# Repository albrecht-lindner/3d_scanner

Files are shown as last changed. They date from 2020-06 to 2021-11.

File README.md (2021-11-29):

# 3d scanner under $40
This project proposes a 3d scanner for distances of up to roughly 10 meters. The scanner uses a smartphone and a line laser module to create colored point clouds. This repository contains hardware and software files.
<br>

The left  image shows the scanner mounted on a tripod and the right image shows the corresponding video frame captured by the smartphone. The horizontal disparity shift of the laser line visible in the video frame is related to the depth of the scene points.

<table style="width:100%; margin:0 auto; border: 0px;">
    <tr>
      <th>setup</th>
      <th>video frame</th> 
    </tr>
    <tr>
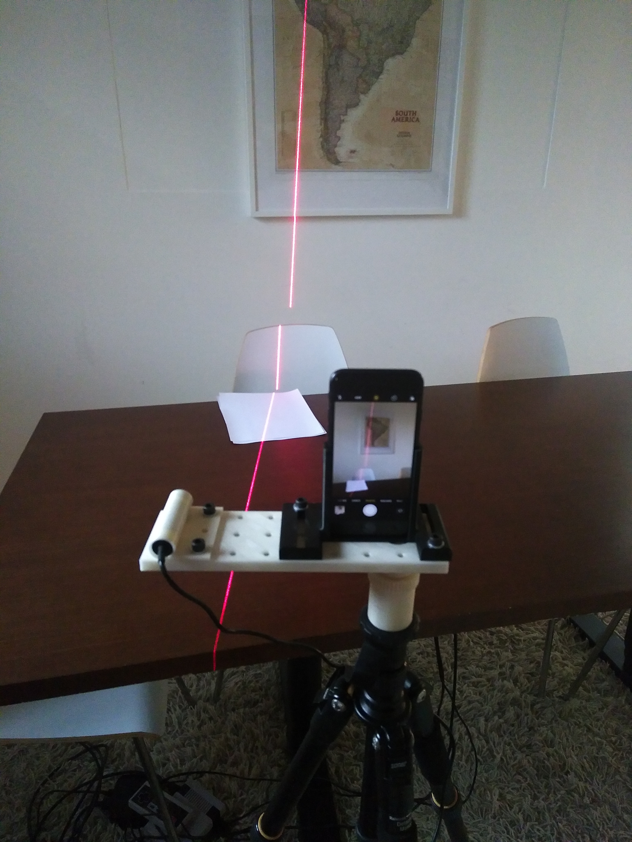
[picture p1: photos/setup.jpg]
      <td></td>
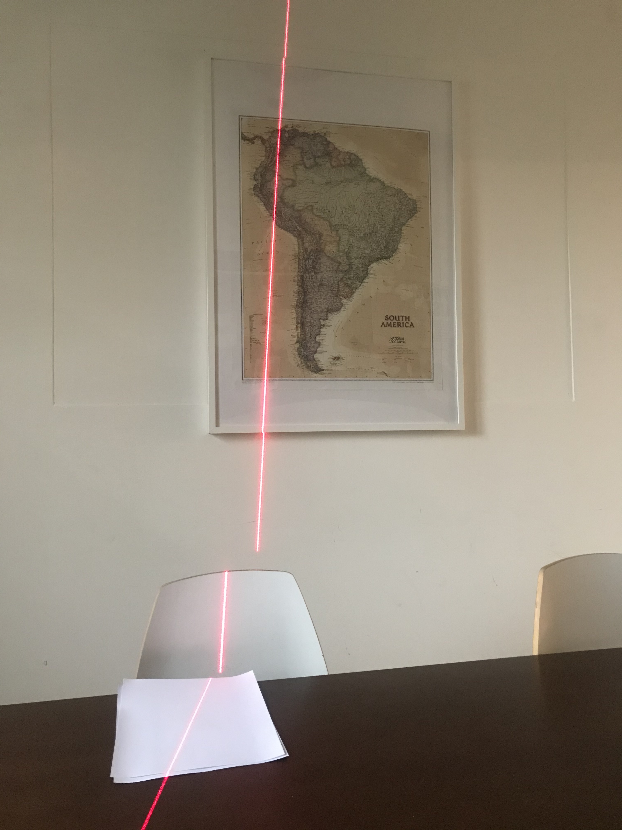
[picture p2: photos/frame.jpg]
      <td> </td> 
    </tr>
</table>
<br>

A video has to be recorded while the scanner rotates 360 degrees around the tripod axis (which coincides with the smartphone camera's optical center). The image below shows 10 key frames of a 360 degree video sequence of an entire room.
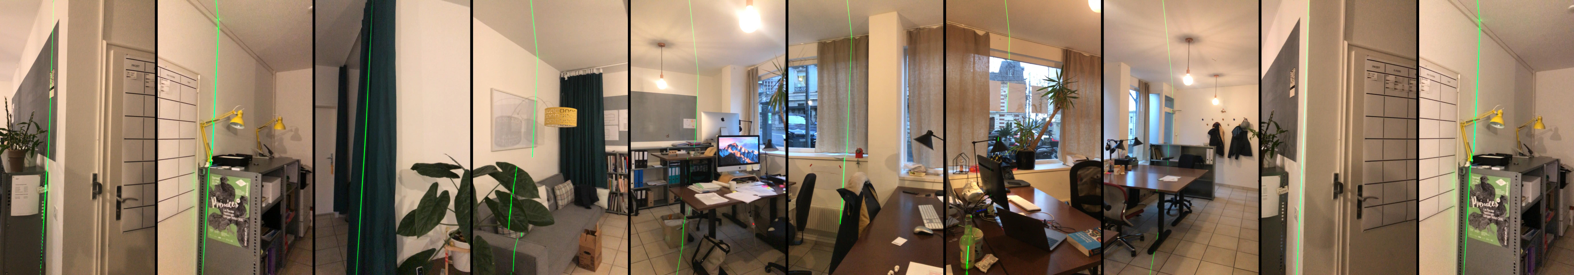
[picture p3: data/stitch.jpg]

<br>

The recorded video can then be converted into a full color 3d point cloud.


Below is a result from another scene. The picture shows the stiched panorama and the corresponding depth map


# Usage
## Run the example video from this repository
- Unzip the video file in the ./data folder
- Run ./software/computePointCloud.m
## Build your own scanner
If you have an iPhone 7 you can use the device holder from the ./hardware folder. If you have another phone you need to design your own holder; make sure the optical center of the camera lies on the rotation axis of the platform, this is crucial.

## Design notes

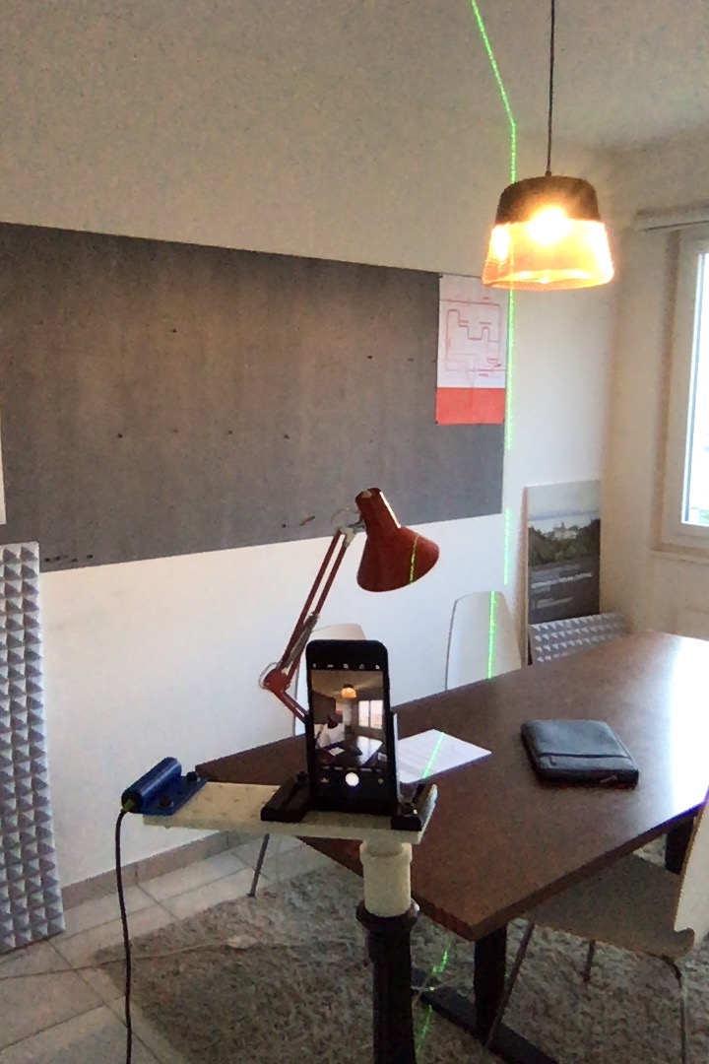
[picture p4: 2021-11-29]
hardware/Photo on 1-21-20 at 9.35 AM.jpg

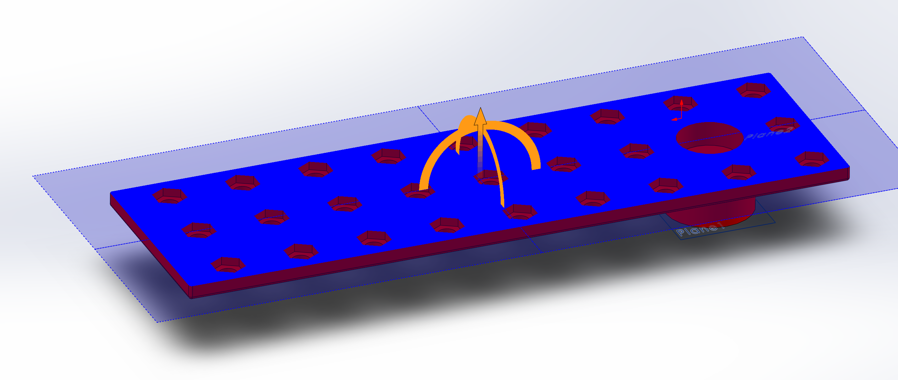
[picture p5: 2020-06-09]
hardware/platform_crossSection.PNG

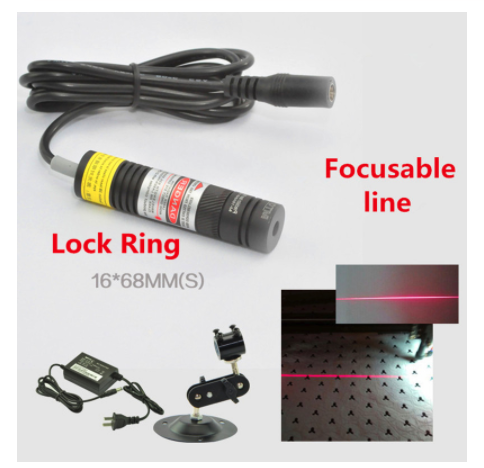
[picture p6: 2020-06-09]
hardware/lineLaserModule.png

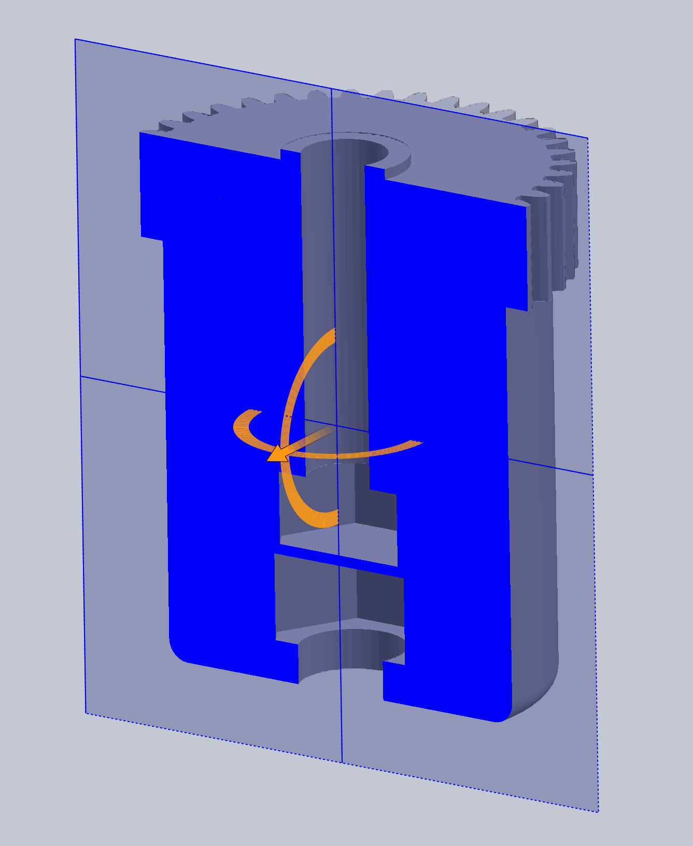
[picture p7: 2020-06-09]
hardware/triodMount_crossSection.PNG

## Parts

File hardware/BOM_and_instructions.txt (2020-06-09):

BOM
2 x 8x22x7 Miniature Ball Bearings
26 x M6 nuts
1 x 1/4-20 nut
1 x M8 nut
1 x M8 screw
6 x M6 screws
1 x Line laser module can be purchased at aliexpress.com for approximately $15 to $25 depending on optical power
1 x Power source for laser module
1 x Tripod with 1/4-20 mount

3d printing
Print all 4 STLs once. Use generic PLA with approximately 30% infill for added stability.

Stop the printing process at the appropriate layer height to insert nuts into the pieces:
platform: 26 x M6 nuts
tripodMount: 1 x 1/4-20 nut (bottomt) and 1 x M8 nut (top)

==========

build instructions
Press fit the ball bearings into the bottom and top holes of the platform. Use the M8 screw to join the platform with the tripod mount.

Using the M6 screws, mount the phone's mounting bracket and the laser holder (with the laser inside) on the platform.

You can now screw the assembly on the tripod and plug in the laser as shown in the photo.

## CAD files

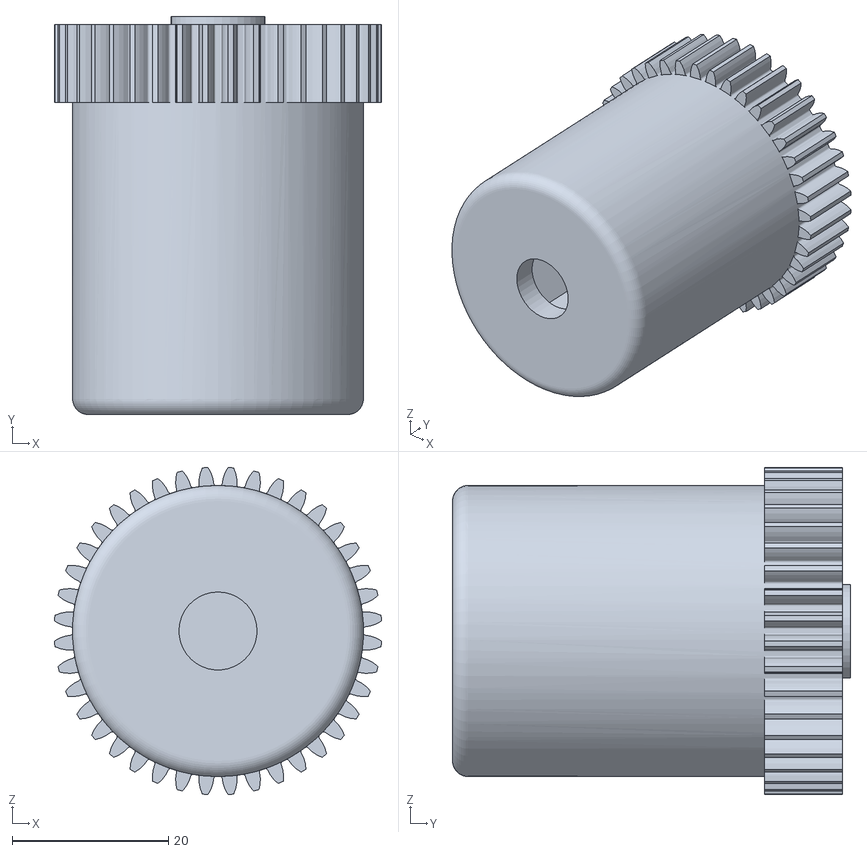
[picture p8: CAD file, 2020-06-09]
hardware/triodMount.STL
41.9 x 51.0 x 41.9

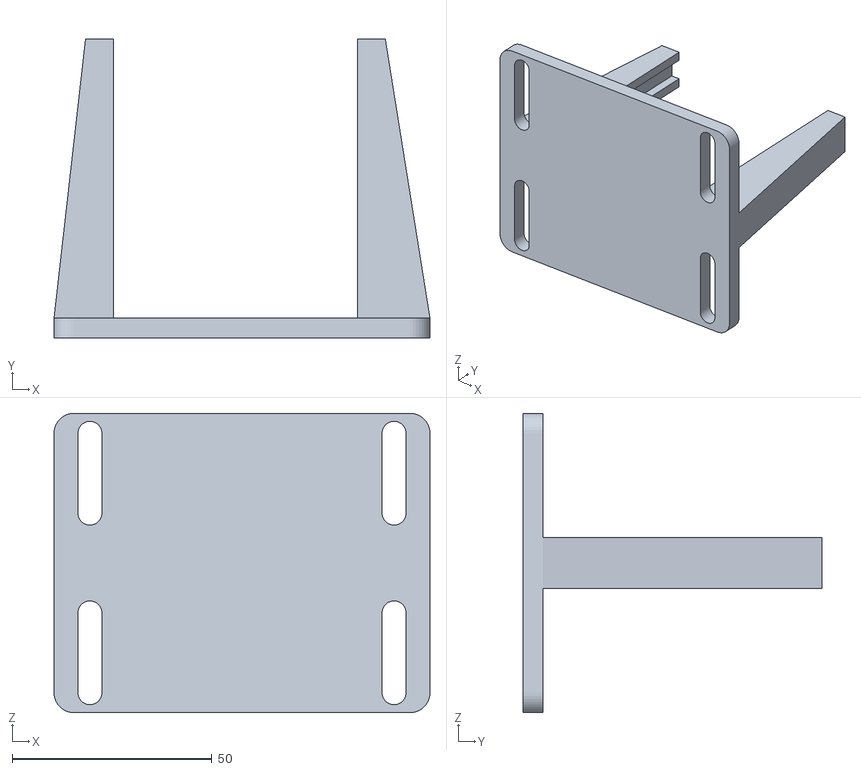
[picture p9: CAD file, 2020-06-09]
hardware/iPhone7_mountingBracket.STL
94.2 x 75.0 x 75.0

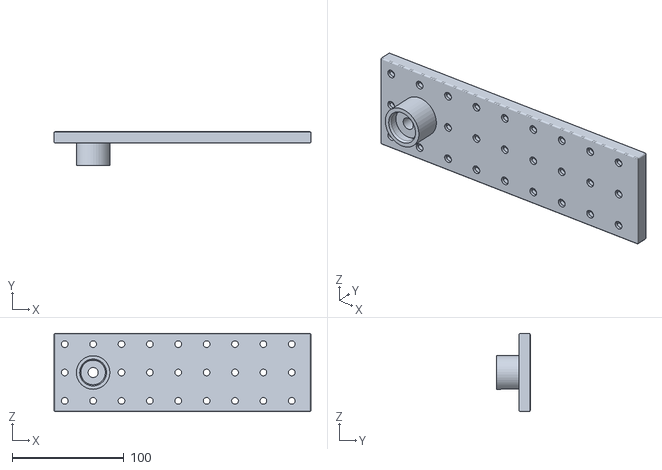
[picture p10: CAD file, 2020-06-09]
hardware/platform.STL
230.0 x 30.0 x 70.0

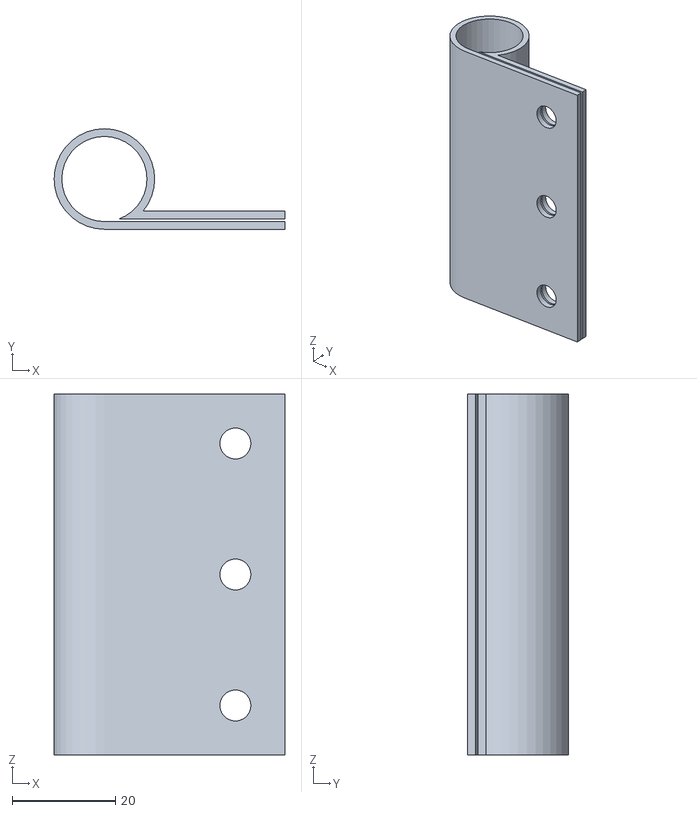
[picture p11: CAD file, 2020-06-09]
hardware/laserHolder.STL
44.7 x 19.5 x 70.0
